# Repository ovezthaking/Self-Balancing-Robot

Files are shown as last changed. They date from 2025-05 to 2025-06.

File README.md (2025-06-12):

# Self-Balancing-Robot
Self balancing robot with arduino nano and 2 motors

If you want to run this code you need to install some required libraries.
How can you install it?
Just move the contents of the "libraries" folder in this repository to:

- For Linux:
/home/user/Arduino/libraries

- For Windows:
My Documents\Arduino\libraries



circuit_image

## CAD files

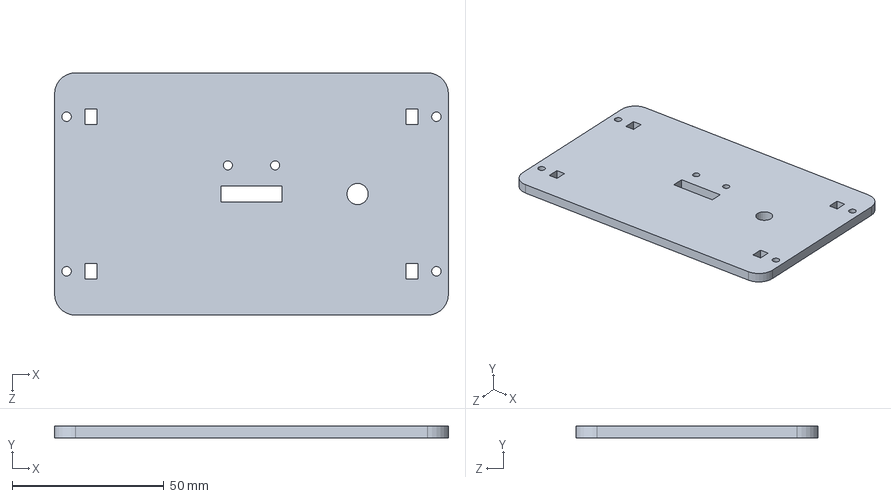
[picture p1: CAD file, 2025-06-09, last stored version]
3D model/top.SLDPRT
130.0 x 4.00 x 80.0 mm

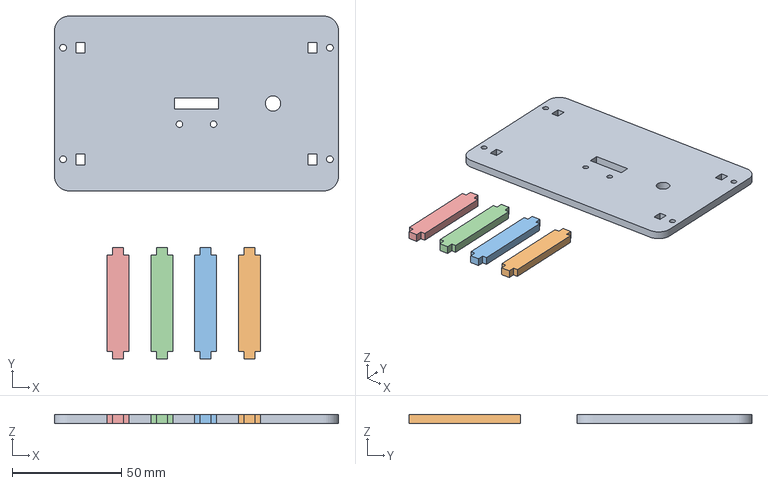
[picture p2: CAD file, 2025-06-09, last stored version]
3D model/New top + spacers.3mf
130.0 x 156.8 x 4.00 mm
top.STL
spacer.STL x 4

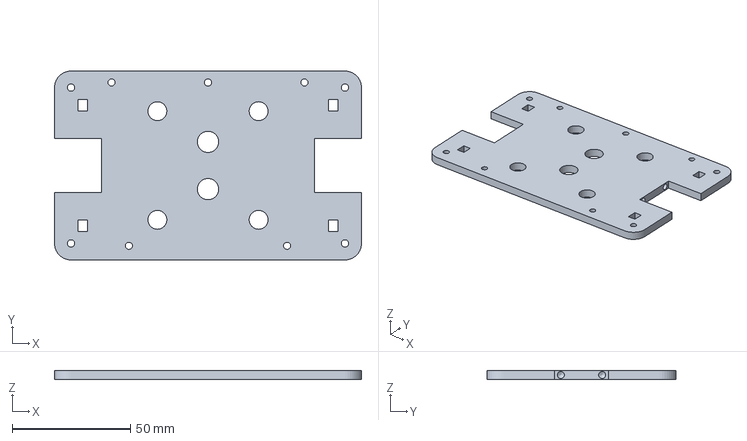
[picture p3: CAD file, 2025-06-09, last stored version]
3D model/Floor only.3mf
130.0 x 80.0 x 4.00 mm

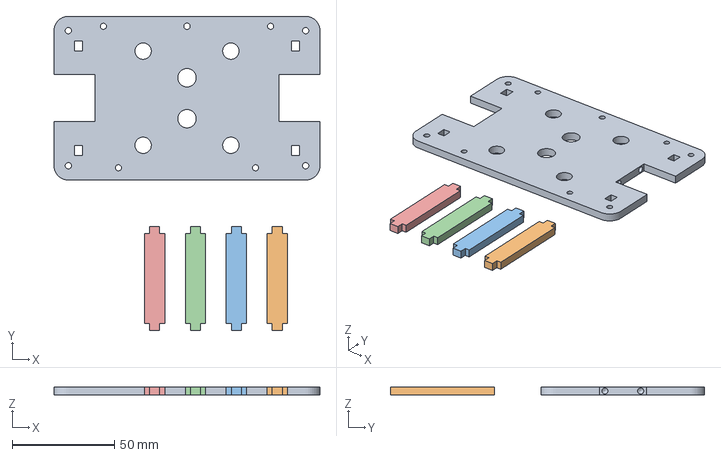
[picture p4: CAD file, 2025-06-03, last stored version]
3D model/Floor + Spacers.3mf
130.0 x 153.6 x 4.00 mm
Floor.STL
spacer.STL x 4

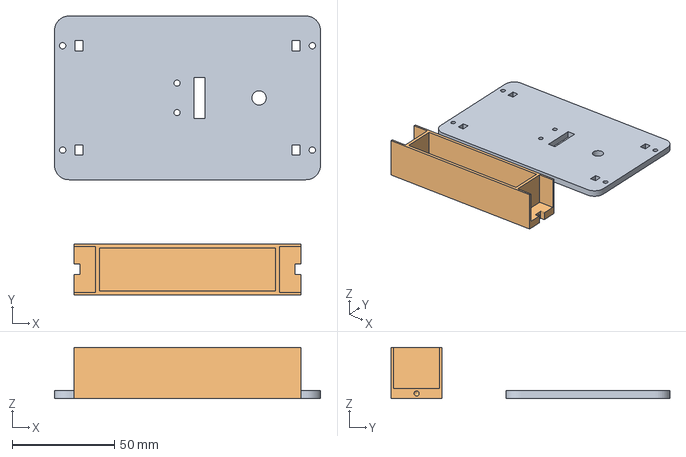
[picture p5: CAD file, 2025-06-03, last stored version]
3D model/Top + case.3mf
130.0 x 136.3 x 25.0 mm
top.STL
18650 li-ion case.STL

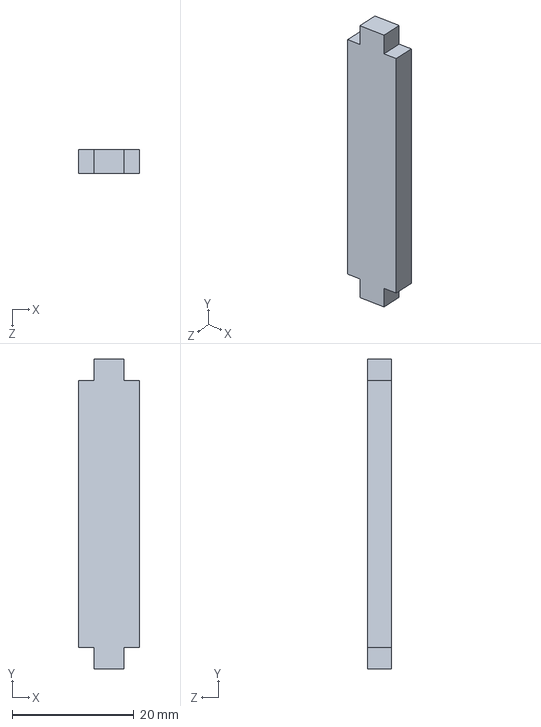
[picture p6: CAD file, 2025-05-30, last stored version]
3D model/spacer.SLDPRT
10.0 x 51.0 x 4.00 mm

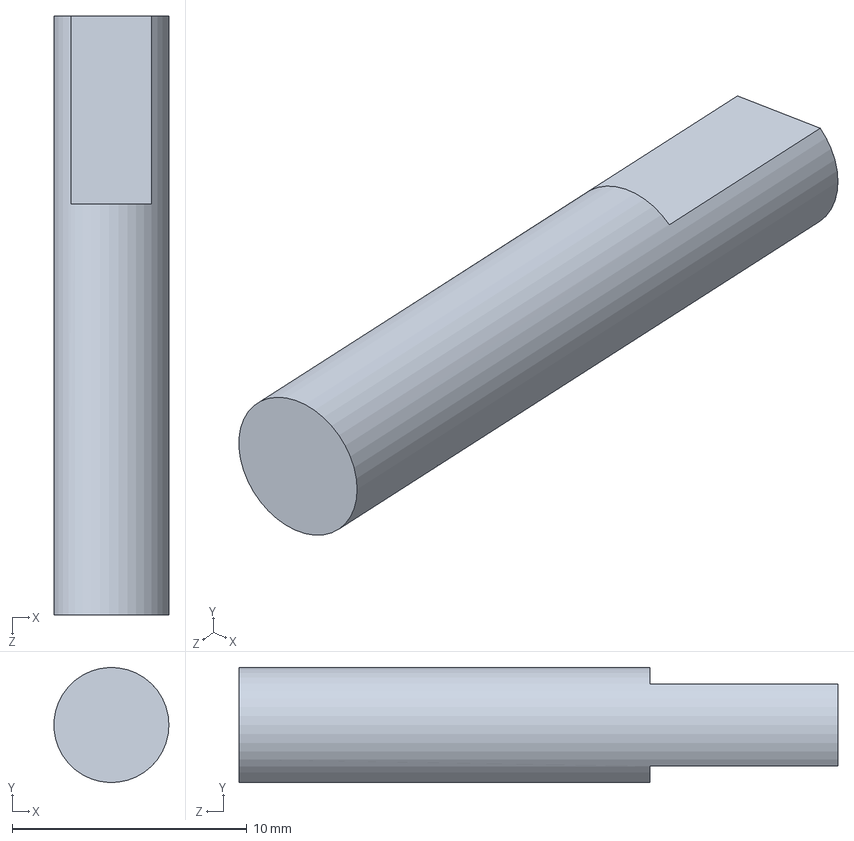
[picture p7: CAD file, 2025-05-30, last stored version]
3D model/Pieza for MOTOR.SLDPRT
4.89 x 4.90 x 25.5 mm

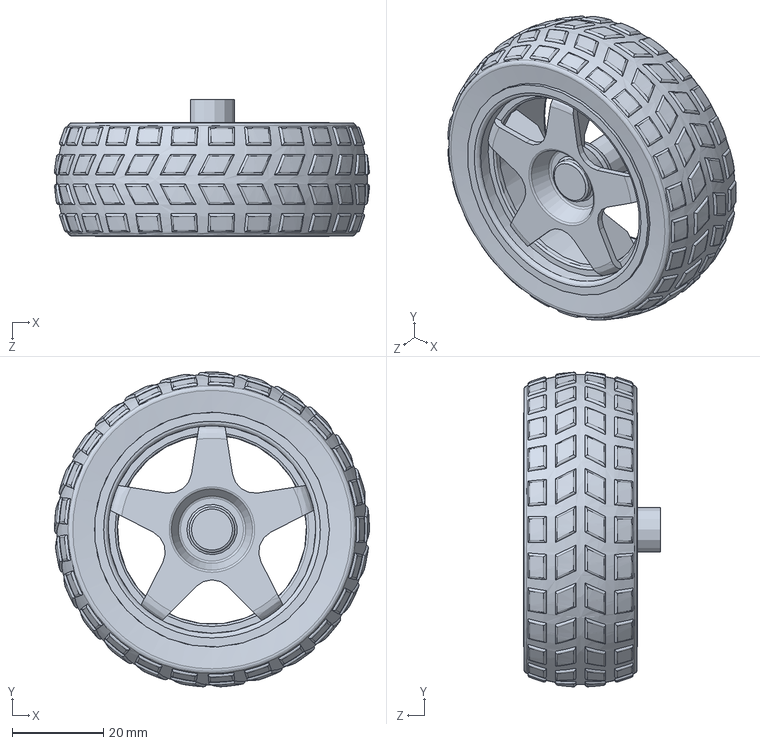
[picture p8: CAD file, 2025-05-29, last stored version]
3D model/Wheel D65x25.SLDPRT
68.9 x 68.8 x 30.0 mm

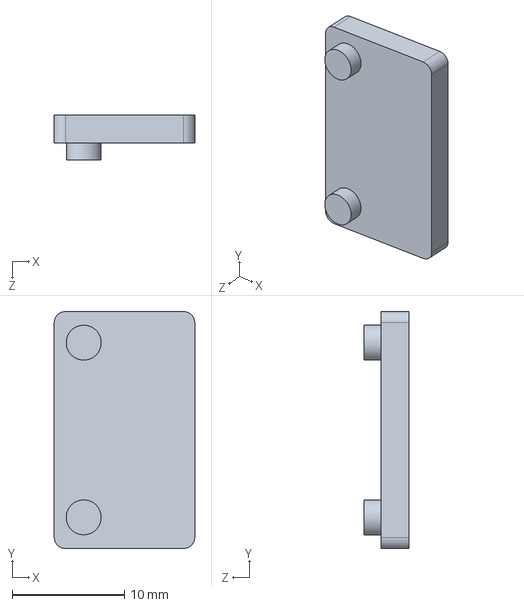
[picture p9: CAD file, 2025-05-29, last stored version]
3D model/mpu 6050 stabilizer.SLDPRT
12.5 x 21.1 x 4.00 mm

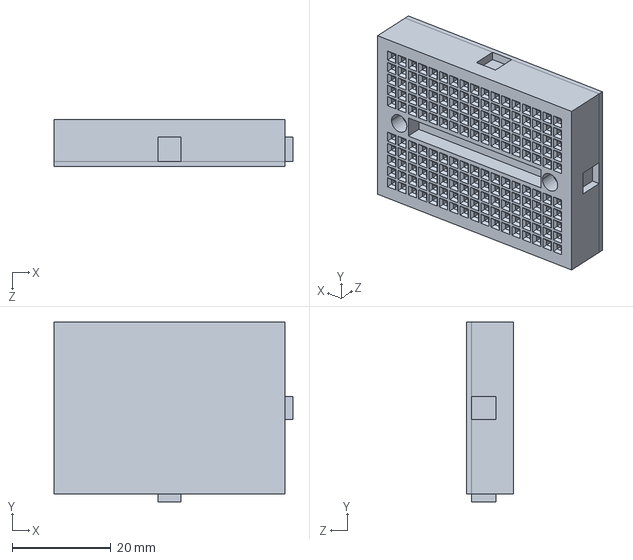
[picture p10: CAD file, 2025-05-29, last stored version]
3D model/breadbord.SLDPRT
48.4 x 36.4 x 9.50 mm

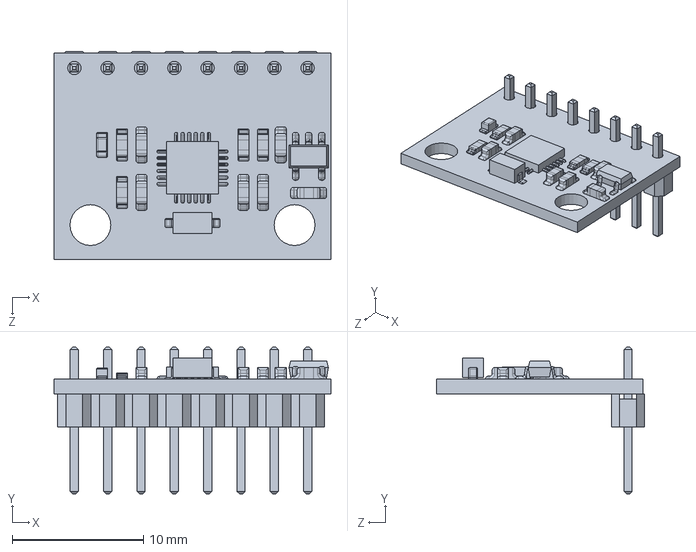
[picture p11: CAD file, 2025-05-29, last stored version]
3D model/mpu6050.SLDPRT
21.1 x 11.2 x 15.9 mm

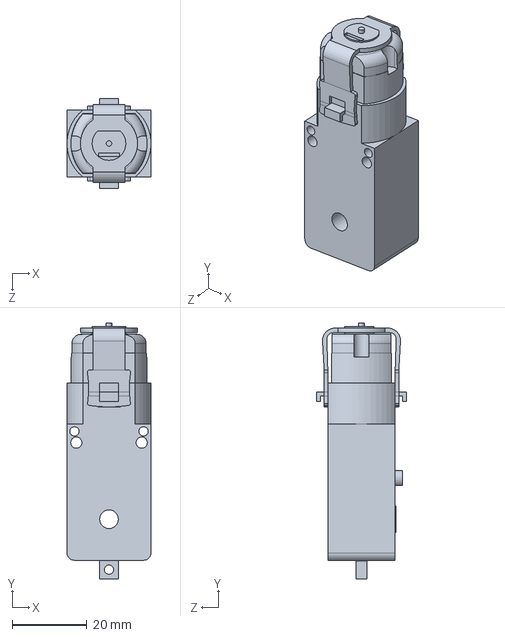
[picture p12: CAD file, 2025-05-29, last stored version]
3D model/MotorDCTT no PIEZA.SLDPRT
22.5 x 68.5 x 24.0 mm

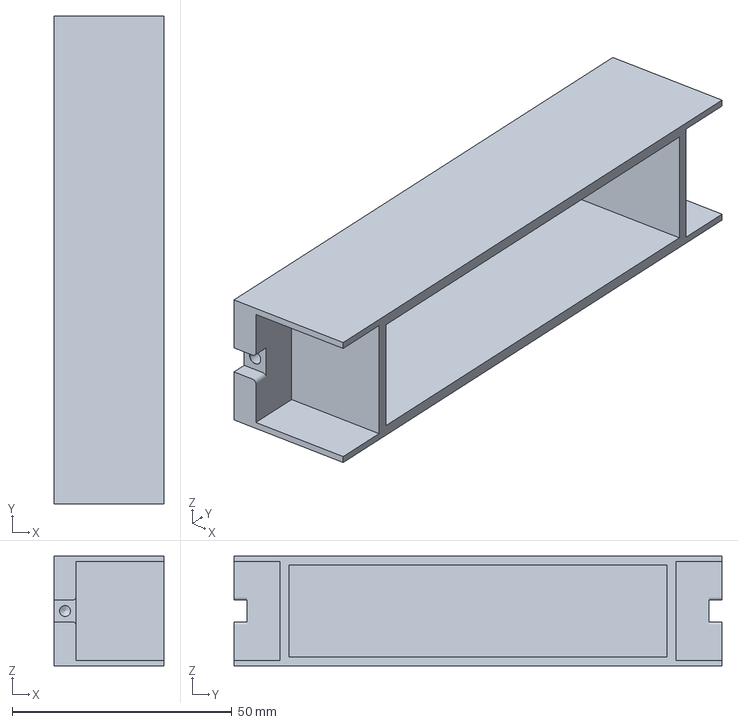
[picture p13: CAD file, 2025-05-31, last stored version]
3D model/18650 li-ion case.3MF
25.0 x 111.0 x 25.0 mm

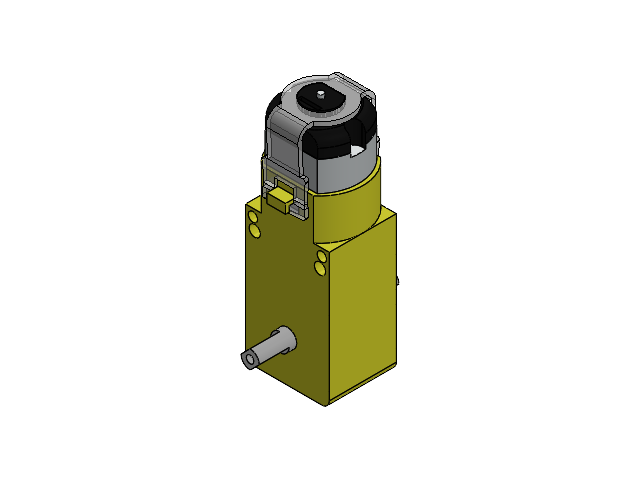
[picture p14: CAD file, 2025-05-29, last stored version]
3D model/EnsamblajeMotorDCTT.SLDASM
MotorDCTT
MotorDCTTPieza

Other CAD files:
3D model/Floor.SLDPRT
3D model/18650 li-ion with case.SLDPRT
3D model/18650 li-ion case.STL
3D model/Floor.3MF
3D model/Floor.STL
3D model/mpu 6050 stabilizer.3mf
3D model/mpu 6050 stabilizer.STL
3D model/spacer.3mf
3D model/spacer.STL
3D model/top.3MF
3D model/top.STL

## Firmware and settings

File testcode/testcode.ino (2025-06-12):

#include <PID_v1.h>
#include <LMotorController.h>
#include "I2Cdev.h"
#include "MPU6050_6Axis_MotionApps20.h"

#if I2CDEV_IMPLEMENTATION == I2CDEV_ARDUINO_WIRE
#include "Wire.h"
#endif

#define MIN_ABS_SPEED 20

MPU6050 mpu;

// MPU control/status vars
bool dmpReady = true;
uint8_t mpuIntStatus;
uint8_t devStatus; //status after each device operation
uint16_t packetSize;
uint16_t fifoCount;
uint8_t fifoBuffer[64];

// orientation/motion vars
Quaternion q;
VectorFloat gravity;
float ypr[3];

//PID
double originalSetpoint = 175.8;
double setpoint = originalSetpoint;
double movingAngleOffset = 0.1;
double input, output;
int moveState = 0; // we'll see

// Detekcja upadku
#define FALL_ANGLE_THRESHOLD 30.0  // kąt w stopniach - jeśli robot jest bardziej przechylony, uznaj za upadek
#define RECOVERY_ANGLE_THRESHOLD 15.0  // kąt powrotu do normalnego działania
bool robotFallen = false;
unsigned long fallStartTime = 0;
#define FALL_TIMEOUT 3000  // 3 sekundy timeout na próbę powrotu

//user's own fit
double Kp = 50;
double Kd = 1.4;
double Ki = 60;
PID pid(&input, &output, &setpoint, Kp, Ki, Kd, DIRECT);

double motorSpeedFactorLeft = 0.9;
double motorSpeedFactorRight = 0.9;

//MOTOR CONTROLLER
int ENA = 5;
int IN1 = 6;
int IN2 = 7;
int IN3 = 8;
int IN4 = 9;
int ENB = 10;
LMotorController motorController(ENA, IN1, IN2, ENB, IN3, IN4, motorSpeedFactorLeft, motorSpeedFactorRight);

long time1Hz = 0;
long time5Hz = 0;

volatile bool mpuInterrupt = false;
void dmpDataReady()
{
  mpuInterrupt = true;
}

void setup()
{
#if I2CDEV_IMPLEMENTATION == I2CDEV_ARDUINO_WIRE
  Wire.begin();
  TWBR = 24;
#elif I2CDEV_IMPLEMENTATION == I2CDEV_BUILTIN_FASTWIRE
  Fastwire::setup(400, true);
#endif

  Serial.begin(115200);
  while (!Serial);

  Serial.println(F("Initializing I2C devices..."));
  mpu.initialize();

  Serial.println(F("Testing device connections..."));
  Serial.println(mpu.testConnection() ? F("MPU6050 connection successful") : F("MPU6050 connection failed"));

  Serial.println(F("Initializing DMP..."));
  devStatus = mpu.dmpInitialize();

  // WAŻNE: Offset dla obróconych osi - dostosuj te wartości do swojego modułu
  // Po obróceniu o 90° w yaw, osie X i Y są zamienione
  mpu.setXGyroOffset(76);    // była wartość Y
  mpu.setYGyroOffset(-220);  // była wartość X z przeciwnym znakiem
  mpu.setZGyroOffset(-85);   // Z pozostaje bez zmian
  mpu.setZAccelOffset(1788);

  if (devStatus == 0)
  {
    Serial.println(F("Enabling DMP..."));
    mpu.setDMPEnabled(true);

    Serial.println(F("Enabling interrupt detection (Arduino external interrupt 0)..."));
    attachInterrupt(0, dmpDataReady, RISING);
    mpuIntStatus = mpu.getIntStatus();

    Serial.println(F("DMP ready! Waiting for first interrupt..."));
    dmpReady = true;

    packetSize = mpu.dmpGetFIFOPacketSize();

    //setup PID
    pid.SetMode(AUTOMATIC);
    pid.SetSampleTime(10);
    pid.SetOutputLimits(-255, 255);
  }
  else
  {
    // ERROR!
    Serial.print(F("DMP Initialization failed (code "));
    Serial.print(devStatus);
    Serial.println(F(")"));
  }
}

void loop()
{
  if (!dmpReady) return;

  while (!mpuInterrupt && fifoCount < packetSize)
  {
    // Sprawdź czy robot nie upadł przed obliczeniem PID
    if (!robotFallen) {
      pid.Compute();
      motorController.move(output, MIN_ABS_SPEED);
    } else {
      // Robot upadł - zatrzymaj silniki
      motorController.move(0, 0);
      
      // Sprawdź timeout - jeśli robot leży zbyt długo, zatrzymaj całkowicie
      if (millis() - fallStartTime > FALL_TIMEOUT) {
        Serial.println(F("Robot fallen - timeout reached, stopping motors"));
        motorController.move(0, 0);
        delay(100);  // krótka pauza
      }
    }
  }

  mpuInterrupt = false;
  mpuIntStatus = mpu.getIntStatus();
  fifoCount = mpu.getFIFOCount();

  if ((mpuIntStatus & 0x10) || fifoCount == 1024)
  {
    mpu.resetFIFO();
    Serial.println(F("FIFO overflow!"));
  }
  else if (mpuIntStatus & 0x02)
  {
    while (fifoCount < packetSize) fifoCount = mpu.getFIFOCount();

    mpu.getFIFOBytes(fifoBuffer, packetSize);
    fifoCount -= packetSize;

    mpu.dmpGetQuaternion(&q, fifoBuffer);
    mpu.dmpGetGravity(&gravity, &q);
    mpu.dmpGetYawPitchRoll(ypr, &q, &gravity);

    // PROSTSZE PODEJŚCIE: Bezpośrednie dodanie 90° do yaw
    // Standardowy odczyt YPR
    mpu.dmpGetQuaternion(&q, fifoBuffer);
    mpu.dmpGetGravity(&gravity, &q);
    mpu.dmpGetYawPitchRoll(ypr, &q, &gravity);
    
    // Dodaj 90° (π/2 radianów) do yaw
    ypr[0] += M_PI/2;
    
    // Normalizuj do zakresu -π do π
    if (ypr[0] > M_PI) ypr[0] -= 2*M_PI;
    if (ypr[0] < -M_PI) ypr[0] += 2*M_PI;

    input = ypr[1] * 180 / M_PI + 180;
    
    // DETEKCJA UPADKU
    float currentAngle = abs(ypr[1] * 180 / M_PI);  // pitch w stopniach (bezwzględna wartość)
    
    if (!robotFallen) {
      // Robot normalnie działa - sprawdź czy nie upadł
      if (currentAngle > FALL_ANGLE_THRESHOLD) {
        robotFallen = true;
        fallStartTime = millis();
        Serial.print(F("Robot fallen! Angle: "));
        Serial.println(currentAngle);
        
        // Zatrzymaj silniki natychmiast
        motorController.move(0, 0);
        
        // Reset PID aby uniknąć nagromadzonego błędu
        pid.SetMode(MANUAL);
        output = 0;
        pid.SetMode(AUTOMATIC);
      }
    } else {
      // Robot upadł - sprawdź czy się podniósł
      if (currentAngle < RECOVERY_ANGLE_THRESHOLD) {
        robotFallen = false;
        Serial.println(F("Robot recovered!"));
        
        // Reset PID na świeży start
        pid.SetMode(MANUAL);
        output = 0;
        pid.SetMode(AUTOMATIC);
      }
    }

#if LOG_INPUT
    Serial.print("ypr\t");
    Serial.print(ypr[0] * 180 / M_PI);
    Serial.print("\t");
    Serial.print(ypr[1] * 180 / M_PI);
    Serial.print("\t");
    Serial.print(ypr[2] * 180 / M_PI);
    Serial.print("\tFallen: ");
    Serial.println(robotFallen ? "YES" : "NO");
#endif
  }
}

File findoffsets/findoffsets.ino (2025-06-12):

/*
  IMU Zero

  Calibrates the MPU6050 to compensate for measurement deviations or errors that may
  occur due to factors such as gyroscope and accelerometer offset.

  When running this example, the code adjusts the MPU6050 sensor's acceleration (X,Y,Z)
  and rotation (gyroscope) axis offset values to ensure that the readings are as accurate as
  possible when the device is at rest.

  To get better results consider:
  1. The MPU6050 module is working fine.
  2. Put the MPU6050 on a flat and horizontal surface, and leave it operating for 
  5-10 minutes so its temperature gets stabilized.
  4. Is in a location where the pull of gravity is 1g.

  During the execution it will generate a dozen outputs, showing that for each of the 6 
  desired offsets, it is:
  - First, try to find two estimates, one too low and one too high.
  - Closing in until the bracket can't be made smaller.

  The line just above the "done" (it will take a few minutes to get there) describes the 
  optimum offsets for the X acceleration, Y acceleration, Z acceleration, X gyro, Y gyro, 
  and Z gyro, respectively.

  Find the full MPU6050 library documentation here:
  https://github.com/ElectronicCats/mpu6050/wiki
*/

#include "I2Cdev.h"
#include "MPU6050.h"

/* Create the class for MPU6050. Default I2C address is 0x68 */
MPU6050 mpu;
// MPU6050 mpu(0x69); // <-- use for AD0 high

const int usDelay = 3150; // Delay in ms to hold the sampling at 200Hz
const int NFast = 1000; // Number of quick readings for averaging, the higher the better
const int NSlow = 10000; // Number of slow readings for averaging, the higher the better
const int LinesBetweenHeaders = 5;

const int iAx = 0;
const int iAy = 1;
const int iAz = 2;
const int iGx = 3;
const int iGy = 4;
const int iGz = 5;

int LowValue[6];
int HighValue[6];
int Smoothed[6];
int LowOffset[6];
int HighOffset[6];
int Target[6];
int LinesOut;
int N;
int i;

void setup() {
  Initialize(); //Initializate and calibrate the sensor
  for (i = iAx; i <= iGz; i++) { 
    Target[i] = 0; // Fix for ZAccel 
    HighOffset[i] = 0;
    LowOffset[i] = 0;
  } 
  Target[iAz] = 16384; // Set the taget for Z axes
  SetAveraging(NFast); // Fast averaging
  PullBracketsOut();
  PullBracketsIn();
  Serial.println("-------------- DONE --------------");
}

void loop() {
  //Write your code here
} 

/*Initializate function*/
void Initialize() {
  #if I2CDEV_IMPLEMENTATION == I2CDEV_ARDUINO_WIRE
    Wire.begin();
  #elif I2CDEV_IMPLEMENTATION == I2CDEV_BUILTIN_FASTWIRE
    Fastwire::setup(400, true);
  #endif
  Serial.begin(115200);
  // Init the module
  Serial.println("Initializing MPU...");
  mpu.initialize();
  Serial.println("MPU initializated");
  // Check module connection
  Serial.println("Testing device connections...");
  if(mpu.testConnection() ==  false){
    Serial.println("MPU6050 connection failed");
  while(true);
  }
  else{
    Serial.println("MPU6050 connection successful");
  }

  Serial.println("\nPID tuning Each Dot = 100 readings");
  /*
  PID tuning (actually PI) works like this: changing the offset in the MPU6050 gives instant results, 
  allowing us to use the Proportional and Integral parts of the PID to find the ideal offsets. 
  The Integral uses the error from the set point (which is zero) and adds a fraction of this error to 
  the integral value. Each reading reduces the error towards the desired offset. The greater 
  the error, the more we adjust the integral value. 
  
  The Proportional part helps by filtering out noise from the integral calculation. The Derivative part is 
  not used due to noise and the sensor being stationary. With the noise removed, the integral value stabilizes 
  after about 600 readings. At the end of each set of 100 readings, the integral value is used for the actual 
  offsets, and the last proportional reading is ignored because it reacts to any noise.
  */
  Serial.println("\nXAccel\t\tYAccel\t\tZAccel\t\tXGyro\t\tYGyro\t\tZGyro");
  mpu.CalibrateAccel(6);
  mpu.CalibrateGyro(6);
  Serial.println("\n600 Readings");
  mpu.PrintActiveOffsets();
  mpu.CalibrateAccel(1);
  mpu.CalibrateGyro(1);
  Serial.println("700 Total Readings");
  mpu.PrintActiveOffsets();
  mpu.CalibrateAccel(1);
  mpu.CalibrateGyro(1);
  Serial.println("800 Total Readings");
  mpu.PrintActiveOffsets();
  mpu.CalibrateAccel(1);
  mpu.CalibrateGyro(1);
  Serial.println("900 Total Readings");
  mpu.PrintActiveOffsets();
  mpu.CalibrateAccel(1);
  mpu.CalibrateGyro(1);
  Serial.println("1000 Total Readings");
  mpu.PrintActiveOffsets();
  Serial.println("\nAny of the above offsets will work nicely \n\nProving the PID with other method:");
}

void SetAveraging(int NewN) {
  N = NewN;
  Serial.print("\nAveraging ");
  Serial.print(N);
  Serial.println(" readings each time");
}

void PullBracketsOut() {
  boolean Done = false;
  int NextLowOffset[6];
  int NextHighOffset[6];

  Serial.println("Expanding:");
  ForceHeader();

  while (!Done) {
    Done = true;
    SetOffsets(LowOffset); //Set low offsets
    GetSmoothed();
    for (i = 0; i <= 5; i++) { // Get low values
      LowValue[i] = Smoothed[i];
      if (LowValue[i] >= Target[i]) {
        Done = false;
        NextLowOffset[i] = LowOffset[i] - 1000;
      } 
      else {
        NextLowOffset[i] = LowOffset[i];
      }
    }
    SetOffsets(HighOffset);
    GetSmoothed();
    for (i = 0; i <= 5; i++) { // Get high values
      HighValue[i] = Smoothed[i];
      if (HighValue[i] <= Target[i]) {
        Done = false;
        NextHighOffset[i] = HighOffset[i] + 1000;
      } 
      else {
        NextHighOffset[i] = HighOffset[i];
      }
    } 
    ShowProgress();
    for (int i = 0; i <= 5; i++) {
      LowOffset[i] = NextLowOffset[i]; 
      HighOffset[i] = NextHighOffset[i];
    }
  }
}

void PullBracketsIn() {
  boolean AllBracketsNarrow;
  boolean StillWorking;
  int NewOffset[6];

  Serial.println("\nClosing in:");
  AllBracketsNarrow = false;
  ForceHeader();
  StillWorking = true;
  while (StillWorking) {
    StillWorking = false;
    if (AllBracketsNarrow && (N == NFast)) {
      SetAveraging(NSlow);
    } 
    else {
      AllBracketsNarrow = true;
    }
    for (int i = 0; i <= 5; i++) {
      if (HighOffset[i] <= (LowOffset[i] + 1)) {
        NewOffset[i] = LowOffset[i];
      } 
      else { // Binary search
        StillWorking = true;
        NewOffset[i] = (LowOffset[i] + HighOffset[i]) / 2;
        if (HighOffset[i] > (LowOffset[i] + 10)) {
          AllBracketsNarrow = false;
        }
      } 
    }
    SetOffsets(NewOffset);
    GetSmoothed();
    for (i = 0; i <= 5; i++) { // Closing in
      if (Smoothed[i] > Target[i]) { // Use lower half
        HighOffset[i] = NewOffset[i];
        HighValue[i] = Smoothed[i];
      } 
      else { // Use upper half
        LowOffset[i] = NewOffset[i];
        LowValue[i] = Smoothed[i];
      } 
    }
    ShowProgress();
  } 
} 

void ForceHeader() {
  LinesOut = 99;
}
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

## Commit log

2025-05-29 3D model starting
    [18650 li-ion with case.SLDPRT, EnsamblajeMotorDCTT.SLDASM, MotorDCTT no PIEZA.SLDPRT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]
2025-05-29 floor and some assembled things
    [Floor.SLDPRT]
2025-05-30 new idea
    [Pieza for MOTOR.SLDPRT]
2025-05-30 battery under floor
    [18650 li-ion with case.SLDPRT]
2025-05-30 Almost assembled
    [top.SLDPRT]
2025-05-30 all components hiden, only for 3D print, finished maybe
    [18650 li-ion with case.SLDPRT, spacer.STL]
2025-05-31 3D models for print ready
    [18650 li-ion case.3MF, 18650 li-ion case.STL, Floor.3MF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]
2025-06-03 gcode and print
    [Floor + Spacers.3mf, Top + case.3mf]
2025-06-03 a little fix, mpu gcode
    [mpu 6050 stabilizer.3mf, mpu 6050 stabilizer.STL]
2025-06-09 new top bcs of its bad position :(
    [New top + spacers.3mf, top.SLDPRT, top.STL]
2025-06-11 new code for yaw 90 degree MPU
2025-10-28 compress g-code and CAD files)
    [18650 li-ion case.3MF, 18650 li-ion case.STL, 18650 li-ion with case.SLDPRT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]
